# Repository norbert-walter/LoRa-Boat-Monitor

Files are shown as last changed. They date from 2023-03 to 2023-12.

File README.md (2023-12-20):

## LoRa Boat Monitor

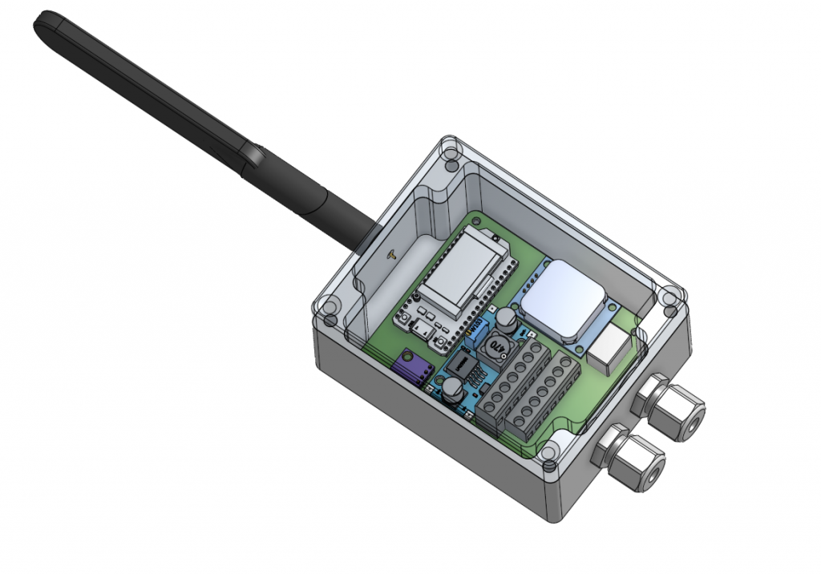
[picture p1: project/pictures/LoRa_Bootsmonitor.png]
LoRa Boat Monitor


Image: LoRa Boat Monitor

Project home page: https://open-boat-projects.org/en/lora-bootsmonitor/

The LoRa boat monitor is used to monitor the boat when it is absent. Various measured values are continuously recorded at freely adjustable time intervals and transferred to the [LoRaWAN](https://www.lora-wan.de/) forwarded. The data is from the TTN server ([The Thinks Network](https://thethingsnetwork.org/)) received in Amsterdam and cached and then sent to [Ubidots](https://ubidots.com/) forwarded as a web frontend. The data transmission is secured by encryption up to Ubidots. The measured data is displayed in Ubidots and various notifications can be sent by email when measured values are exceeded.

There are a large number of [LoRa gateways](https://thethingsnetwork.org/map) which can receive the sent measurement data and forward it to the TTN server. Many LoRa gateways are run by private individuals on a non-profit basis. Anyone who wants can operate their own gateway and make it available to the general public. The radio technology uses the license-free frequency range around 868 MHz and uses a special transmission technology (chirp) to achieve large ranges of up to 50 km at low data rates. The ranges depend on the type of transmission, the antenna height and the environment. In built-up areas such as cities, typical ranges of 1… 4 km are possible. In open environments such as lakes and the sea, up to 50 km can be reached. There are no costs for data transmission when sending LoRa telegrams. This is the big difference to other long range transmission technologies like [SIGFOX](https://www.sigfox.com/) and mobile data networks such as 3G / 4G / 5G. If no LoRa gateway is within range, a simple 1-channel or 3-channel LoRa gateway can be set up with the same board. Only a few components are then left out and a different firmware used. Alternatively, the measured values can also be sent directly to Ubidots via WLAN, provided that a WLAN is within range.

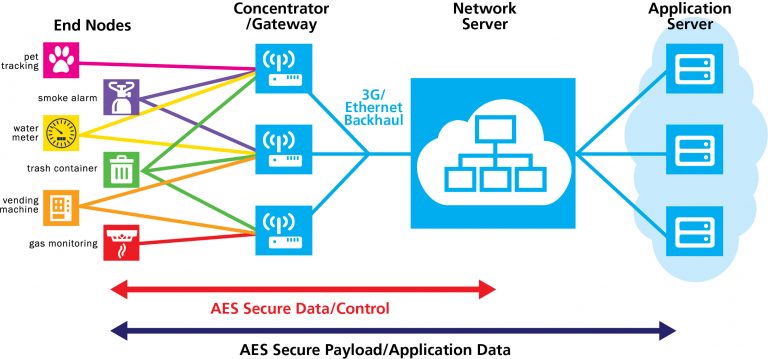
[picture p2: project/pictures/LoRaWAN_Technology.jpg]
LoRa Data Transmission


Image: LoRa data transmission Semtech GmbH

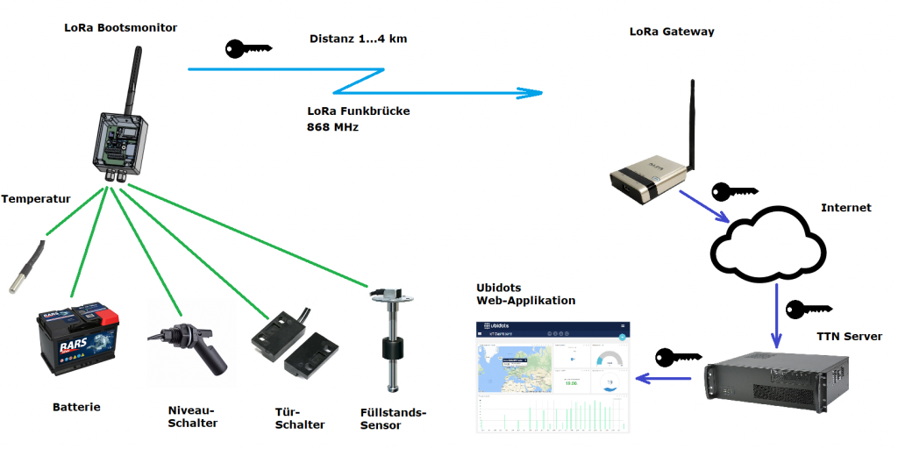
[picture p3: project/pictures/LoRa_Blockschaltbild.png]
LoRa Data Transmission


Image: Block diagram LoRa boat monitor

## The LoRa boat monitor has the following functions:

* 10… 32V supply voltage
* 1.2W power consumption
* LoRa transmitter and receiver with OLED display
* 868 MHz, SF7… SF12, 100 mW transmission power
* Dynamic spreeding factor adjustable SF7… FS10
* Supports channel 0...7 dynamic and fix
* Data transfer rate: 0.3 to 50 kbit / s
* Max. Telegram length for user data: 200 bytes
* Range: built-up area 1… 4km, open area up to 50km
* LoRa transmission interval 30s… 2.1h
* One-channel, three-channel and eight-channel modes can be set
* Feeding the data into The Thinks Network (TTN)
* Parameterization of the LoRa boat monitor possible via return channel (channel, SF, transmission interval, relay)
* WLAN (2.4 GHz) for alternative data transmission
* Web interface for operation
* Firmware update possible via WLAN and Internet
* GPS sensor for geographic location coordinates
* BME280 for measuring temperature, humidity and air pressure
* 1x battery voltage measurement (0… 32V service battery)
* 1x potential-free alarm contact eg for bilge and door monitoring
* 2x tank sensors (0 ... 180 Ohm) with percentage display
* Calibratable tank and voltage sensors
* 1x Reais output for potential-free switching of loads with specified time (5min ... 21h) up to 3A (12V or 230V)
* 2x 1Wire connection for temperature sensors DS18B20 for battery monitoring and refrigerator
* Monitoring and alerting via Ubidots web frontend
* Alerting by e-mail if limit values are exceeded via Ubidots
* Automatic data storage for the last 31 days at Ubidots
* Use of cheap embedded modules
* No SMD components on the board and easy to build
* Board can be ordered here:[https://aisler.net/p/GEIYWWXZ](https://aisler.net/p/GEIYWWXZ)
* Android app

## Create your own code

You have the option of creating your own code using the online [software development environment Gitpod](https://gitpod.io/#https://github.com/norbert-walter/LoRa-Boat-Monitor). Follow this link and a finished development environment similar to PlatformIO will be created that runs in your browser with all code components. To compile the software, enter ***bash run*** in the terminal. In the workspace you will find the compiled binary code under ***.pio/build/heltec_wifi_lora_32_V2/firmware.bin***. With a right click you can download the binary file. You need a account for Gitpod.

## Device flash process

With the [Web Flash Tool](https://norbert-walter.github.io/LoRa-Boat-Monitor/flash_tool/esp_flash_tool.html) you can very easily flash the device with the firmware from the web browser. You need a Chrome or Edge browser and a USB connection cable. If the device is connected to the USB port of the computer, the serial connection can be selected and the flash process can then be started.

## How can I use it?

## What is the current status?

I have completed many tasks but still not everything is perfect so far.

- [x] Technical recherche
- [x] Evaluation of function
    - [x] LoRa trasmission tests
    - [x] Accessibility of gateways
    - [x] Measurement of telegram losses 
    - [x] Test spreeding factors
    - [x] Antenna test
    - [x] TTN configuration
    - [x] Ubitots configutarion and restrictions
- [x] Mechanical design
    - [x] 3D parts für Onshape
- [x] Electronic design
    - [x] Circuit design
    - [x] Board design
    - [x] Customer sample circuit
- [ ] Software
    - [x] Basic functionality for LoRa
    - [x] LoRa back channel for configuration
    - [x] Dynamic spreedung factor
    - [x] Voltage measurement
    - [x] Tank sensors
    - [x] GPS modul
    - [x] BME280
    - [x] Alarm sensors
    - [x] Relay function
    - [x] JSON
    - [x] Web-Updater
    - [x] Web-Configurator
    - [x] Web server as data display
    - [x] VE.Direct support for Victron
    - [ ] Ubidots connection via WiFi
    - [x] NMEA0183 WiFi
    - [x] NMEA0183 Serial
    - [ ] MQTT
    - [x] Andoid App
    - [x] LoRa gateway firmware
    - [x] Migration to TTS V3
- [x] Components ordering
    - [x] Electronic board
    - [x] Mechanical parts
    - [x] Fittings
- [x] Prototyp creation
    - [x] LoRa boat monitor
    - [x] LoRa gateway
- [ ] Production Zero series
    - [ ] DIY Kits
    - [x] Assembled LoRa boat monitor
- [x] Shipping Zero Series
- [x] Documentation
    - [x] Documentation and update server on GitLab
    - [x] Technical description
    - [x] Construction manual
    - [x] Part list
    - [x] User manual
    - [x] Data sheet
    - [x] Flash instructions
- [x] Application tests
    - [x] Temperature 20...40°C
    - [x] LoRa range test (SF7...SF12)
    - [x] WiFi stability test
    - [x] Connection test
    - [x] Long time test
    - [x] User experiences
- [ ] Extensions
    - [ ] Battery current sensor
    - [ ] Actions and alarms depends on events and measuring values
    - [ ] Build a LoRa gateway structure on two towers for the IJsselmeer in Netherlands 
- [ ] Certification
    - [ ] CE Certification

## Questions?

For questions or suggestions please get in contact via email at norbert-walter(at)web.de.

If you like to help or consider this project useful, please donate. Thanks for your support!

Donate

[Donate with PayPal](https://www.paypal.com/cgi-bin/webscr?cmd=_s-xclick&hosted_button_id=5QZJZBM252F2L)

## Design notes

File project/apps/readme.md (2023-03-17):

**Info!** The security guidelines are increased under Android 11 and no third-party apps can be installed via download. The app must be saved in the Downloads folder using a USB cable. The app can then be installed with the Google file manager.

**20210630 LoRa_Boatmonitor_1.apk `(stable)`**

* First App version
* If the App running then disable the display timeout

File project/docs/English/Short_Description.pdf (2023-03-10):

LoRa Boat Monitor

Voltage: 12V (reverse polarity protected, 10 ... 35V DC) Current: 0.1A (0.15A with relay on)
Power: 1.2W
Frequency: 868MHz
Transmission power: 100mW
Antenna: λ / 4, 5dBi, SWR 1.50, 868MHz, SMA
LoRa channel: EU868 dynamic 0 ... 7 or fixed 0 ... 7 (adjustable via return channel) US915 / AU915 dynamic 8 ... 15 or fixed 8 ... 15 (adjustable via return channel) Spreading factor: SF7 ... SF12 (adjustable via return channel)
Send interval: every 300s (5min)
Telegram length: 40 bytes (12 measured values)
GPS: 50 channels, -161dBm, 1Hz, max.2.5m resolution, fix = flashing LED Float switch: closed = 0, open = 1
Temp sensor: -55 ... + 125 ° C, moisture-proof
Relay: 12V / 3A (adjustable via return channel with time limit)
5V output: 2A, short-circuit proof, Attention! Do not connect 12V

Buttons and LEDs LoRa Modul

PRG: programming (without function)
RST: Reset the software, also triggers a telegram transmission and resets the counter LED orange: charge status of the Lipo battery (without function, may light up or flicker) LED white: status of the relay (on: relay active, off: relay inactive)
USB: programming and debug messages, 8N1, 115200Bd

Conector

Alarm
+12V

Alarm
GND

Level
sensor 2
signal,
0-180
Ohm

Level
sensor 2
GND
0-180
Ohm

DS18B20
Temp
sensor,
+5V

DS18B20
Temp
sensor,
1Wire

DS18B20
Temp
sensor,
GND
top | AL | AL | TA2 | GND | +5V | 1W | GND
buttom | +12V | GND | TA1 | GND | NC | C | NO
| Power +12V | Power GND | Level sensor 1 signal, 0-180 Ohm | Level sensor 1 GND | Relay Normaly Close | Relay Center | Relais Normaly Open
AL: | Potential-free digital alarm input (0V high / 12V low) Float switch, door contact, etc.
TA1 / 2: | Tank sensor input 0-180 Ohm
| Caution! Do not connect 12V
1W: | 1Wire data line for external temperature sensor DS18B20 (0 ... 3.3V) Temperature
| monitoring for battery
| Caution! Do not connect 12V
Relay: | Potential-free changeover switch for 12 ... 24V / 3A

Display values

A: Alarm input [1 = 0V, 0 = 12V] C: Telegram counter 0...n
D: Dewpoint [°C]
dT: Send interval [s]
H: rel. Humidity [%]
L: Level value 1 [%]
L2: Level value 2 [%]
P: Air pressure [mbar]
R: State Relay
T: Temperature [°C] (BME280)
T2: Temperature extern [°C] (DS18B20) X: GPS Longitude [° dez]
Y: GPS Latitude [° dez]

Decoding Payload

var counter = ((bytes[1] << 8) | bytes[0]);
var temperature = (((bytes[3] << 8) | bytes[2]) / 100) - 50;
var pressure = ((bytes[5] << 8) | bytes[4]) / 10;
var humidity = ((bytes[7] << 8) | bytes[6]) / 100;
var dewpoint = (((bytes[9] << 8) | bytes[8]) / 100) - 50;
var voltage = ((bytes[11] << 8) | bytes[10]) / 100;
var tempbattery = (((bytes[13] << 8) | bytes[12]) / 100) - 50;
var longitude = ((bytes[15] << 8) | bytes[14]) + ((bytes[17] << 8) | bytes[16]) / 10000;
var latitude = ((bytes[19] << 8) | bytes[18]) + ((bytes[21] << 8) | bytes[20]) / 10000;
var level1 = ((bytes[23] << 8) | bytes[22]) / 100;
var level2 = ((bytes[25] << 8) | bytes[24]) / 100;

Coding Return Channel

The following settings can be made with 3 bytes via the LoRa return channel:

- Byte 0 Change relay state with time function
- Byte 1 Setting of the LoRa spreeding factor
- Byte 2 Setting of the transmission interval

The values for the spreeding factor and transmission interval are permanently saved in the EEPROM and are power off save.

Meaning

The settings must be entered as hexadecimal values for TTN. It is not necessary that all bytes are transmitted. The relay status can also be changed with just one byte.

Byte 0: 0x00...0xFF (0=off, 1...255 * 5 min)
Byte 1: 0x07...0x0A (7...10 = SF7...SF10)
Byte 2: 0x01...0xFF (1...255 * 30s)

Sample:

0x02 0x0A 0x0A
|____ Send interval 300s
|__________ Spreeding faktor SF10 |______________ Relay on for 10 min
0x00 | Relay off
0x00 0x07 | Relay off, SF7

The values for Downlink can be entered in the TTN console under Device. Port 1 should be used and the data should be sent with confirmation. The return channel data is only received by the LoRa boat monitor for 2 seconds after the LoRa measured values have been sent out. Depending on the connection quality and the transmission interval setting, it can take several hours until the information is received by the LoRa boat monitor. The relay switch-on time must be selected carefully, as it may not be possible to switch the relay off again for a short time.

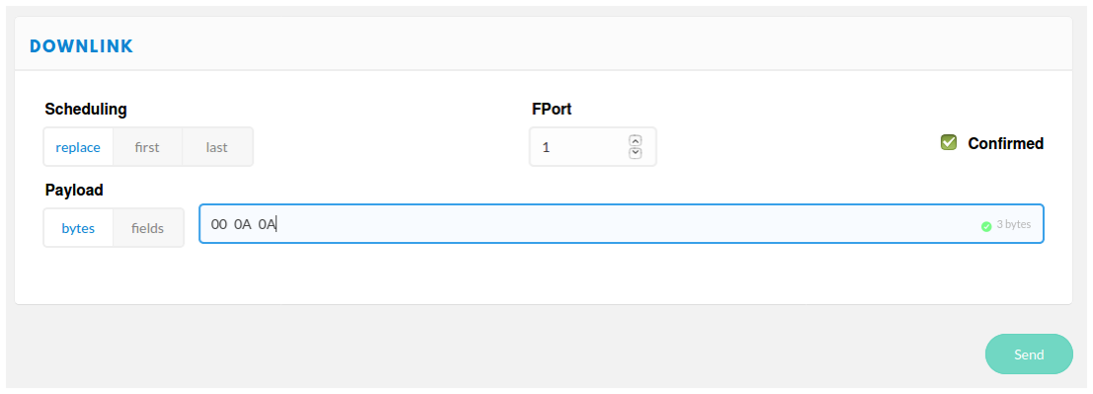
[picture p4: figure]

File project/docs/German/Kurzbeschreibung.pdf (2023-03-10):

LoRa Bootsmonitor

Spannung: 12V (verpolungssicher, 10...35V DC) Strom: 0,1A (0,15A mit Relais an)
Power: 1,2W
Frequenz: 868MHz
Sendeleistung: 100mW
Antenne: λ/4, 5dBi, SWR 1,50, 868MHz, SMA
LoRa-Kanal: EU868 dynamisch 0...7 oder fix 0...7 (über Rückkanal einstellbar) US915 / AU 915 dynamisch 0...7 oder fix 0...7 (über Rückkanal einstellbar) Spreadingfaktor: SF7...SF12 (über Rückkanal einstellbar)
Device-ID: my_device
Device-Address: 12345678
Sendeintervall: alle 300s (5min)
Telegrammlänge: 40 Bytes (12 Messwerte)
GPS: 50 Kanal, -161dBm, 1Hz, max. 2,5m Auflösung, Fix = blinkende LED Schwimmschalter: zu = 0, auf = 1
Tempsensor: -55...+125°C, feuchtigkeitsgeschützt
Relais: 12V / 3A (über Rückkanal mit Zeitbegrenzung einstellbar) 5V-Ausgang: 2A, kurzschlussfest, Achtung! Keine 12V anschließen

Taster und LEDs am LoRa-Modul

PRG: Programmierung (ohne Funktion)
RST: Reset der Software, löst auch eine Telegrammaussendung aus und setzt den Counter zurück LED orange: Ladezustand des Lipo Akkus (ohne Funktion, kann leuchten oder flackern)
LED weiß: Zustand des Relais (an: Relais aktiv, aus: Relais inaktiv)
USB: Programmierung und Debugmeldungen, 8N1, 115200Bd

Klemmenbelegung

Alarm
+12V

Alarm
GND

Tanksensor
2 Signal,
0-180
Ohm

Tanksensor
2 GND
0-180
Ohm

DS18B20
Tempsensor,
+5V

DS18B20
Tempsensor,
1Wire

DS18B20
Tempsensor,
GND
oben | AL | AL | TA2 | GND | +5V | 1W | GND
unten | +12V | GND | TA1 | GND | NC | C | NO
| Power +12V | Power GND | Tanksensor 1 Signal, 0-180 Ohm | Tanksensor 1 GND | Relais Öffner | Relais Mitte | Relais Schließer
AL: | Potenzialfreier digitaler Alarmeingang (0V High / 12V Low) Schwimmschalter, Türkontakt, etc.

TA1/2: Tanksensoreingang 0-180 Ohm
| Achtung! Keine 12V anschließen
1W: 1Wire-Datenleitung für externen Temperatursensor DS18B20 (0...3,3V)
| Temperaturüberwachung für Batterie Achtung! Keine 12V anschließen

Relais: Potenzialfreier Wechselschalter für 12...24V / 3A

Bedeutung im Display

A: Alarmeingang [1 = 0V, 0 = 12V] C: Telegramm-Counter 0...n
D: Taupunkt [°C]
dT: Sendeintervall [s]
H: rel. Luftfeuchtigkeit [%] L: Tankanzeige 1 [%]
L2: Tankanzeige 2 [%]
P: Luftdruck [mbar]
R: Relaiszustand
T: Temperatur [°C] (BME280)
T2: Temperatur extern [°C] (DS18B20) X: GPS Longitude [° dez]
Y: GPS Latitude [° dez]

Dekodierung der Payload

var counter = ((bytes[1] << 8) | bytes[0]);
var temperature = (((bytes[3] << 8) | bytes[2]) / 100) - 50;
var pressure = ((bytes[5] << 8) | bytes[4]) / 10;
var humidity = ((bytes[7] << 8) | bytes[6]) / 100;
var dewpoint = (((bytes[9] << 8) | bytes[8]) / 100) - 50;
var voltage = ((bytes[11] << 8) | bytes[10]) / 100;
var tempbattery = (((bytes[13] << 8) | bytes[12]) / 100) - 50;
var longitude = ((bytes[15] << 8) | bytes[14]) + ((bytes[17] << 8) | bytes[16]) / 10000;
var latitude = ((bytes[19] << 8) | bytes[18]) + ((bytes[21] << 8) | bytes[20]) / 10000;
var level1 = ((bytes[23] << 8) | bytes[22]) / 100;
var level2 = ((bytes[25] << 8) | bytes[24]) / 100;

Codierung Rückkanal

Über den LoRa-Rückkanal können mit 3 Bytes folgende Einstellungen vorgenommen werden:

- Byte 0 Relais-Zustand ändern mit Zeitfunktion
- Byte 1 Einstellung des LoRa-Spreeding-Faktors
- Byte 2 Einstellung des Sendeintervalls

Die Werte für Sreeding-Faktor und Sendeintervall werden dauerhaft im EEPROM gespeichert und sind Power Off save.

Bedeutung

Die Einstellungen müssen als hexadezimale Werte bei TTN eingegeben werden. Es ist nicht notwendig, dass alle Bytes übertragen werden. Der Relais-Zustand kann auch nur mit einem Byte verändert werden.

Byte 0: 0x00...0xFF (0=off, 1...255 * 5 min)
Byte 1: 0x07...0x0A (7...10 = SF7...SF10)
Byte 2: 0x01...0xFF (1...255 * 30s)

Beispiele:

0x02 0x0A 0x0A
|____ Sendeintervall 300s
|__________ Spreedingfaktor SF10 |______________ Relais für 10 min einschalten
0x00 | Relais ausschalten
0x00 0x07 | Relais ausschalten, SF7 verwenden

In der TTN-Console unter Device können die Werte bei Downlink eingegeben werden. Es sollte der Port 1 verwendet und die Daten mit Bestätigung (Confirmed) versendet werden. Die Rückkanaldaten werden immer nur 2s lang nach der Telegrammaussenung der LoRa-Messwerte vom LoRa-Bootsmonitor empfangen. Je nach Verbindungsqualität und Sendeintervall-Einstellung kann es mehrere Stunden dauern, bis die Informationen vom LoRa-Bootsmonitor empfangen werden. Die Relais-Einschaltdauer muss entsprechend vorsichtig gewählt werden, da man unter Umständen das Relais nicht wieder kurzfristig ausschalten kann.


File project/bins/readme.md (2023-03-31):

**20230331 firmware_V1.06.bmb `(actual)`**

* Fix for DS18B20
* WLAN default settings (SSID: NoWa, Pass: 12345678, IP: 192.168.4.1)

**20230312 firmware_V1.05.bmb `(old)`**

* Add boot screen
* Add VE.Direct read and write
* Support for Victron devices with VE.Direct port
* Add NMEA0183 sentences for VE.Direct
* Fix for wrong GPS informations
* Cyclic updating of all information on the OLED display
* Add separate task for LoRa functions
* Stable Web sites
* Project changed from GitLab to GitHub
* WLAN default settings (SSID: NoWa, Pass: 12345678, IP: 192.168.4.1)

`Attention! After update changes all settings to default values. Please renew the settings.`

**20221119 firmware_V1.03.bmb `(old)`**

* Fixing hanging GPS data
* Fixing hanging telegram counter
* Fixing a lot of other bugs
* Validate checksum for NMEA0183 GPS Data and validate RMC content for China fake GPS modul with wrong telegrams
* Add a checksum for TTN upload messages
* Add NMEA0183 output on port 6666 for measuring and GPS values
* All measuring values update permantent on OLED
* Support TTN V3 (TTS)
* WLAN default settings (SSID: NoWa, Pass: 12345678, IP: 192.168.4.1)

`Attention! After update changes all settings to default values. Please renew the settings.`

**20210616 firmware_V1.01.bmb `(old)`**

* Add page for device info, LoRa info and sensor values
* WLAN default settings (SSID: NoWa, Pass: 12345678, IP: 192.168.4.1)

`Attention! After update changes all settings to default values. Please renew the settings.`

**20210530 firmware_V1.00.bmb `(old)`**

* Initial firmware with limited functionality (only settings, no view for measuring results)
* WLAN default settings (SSID: NoWa, Pass: 12345678, IP: 192.168.4.1)

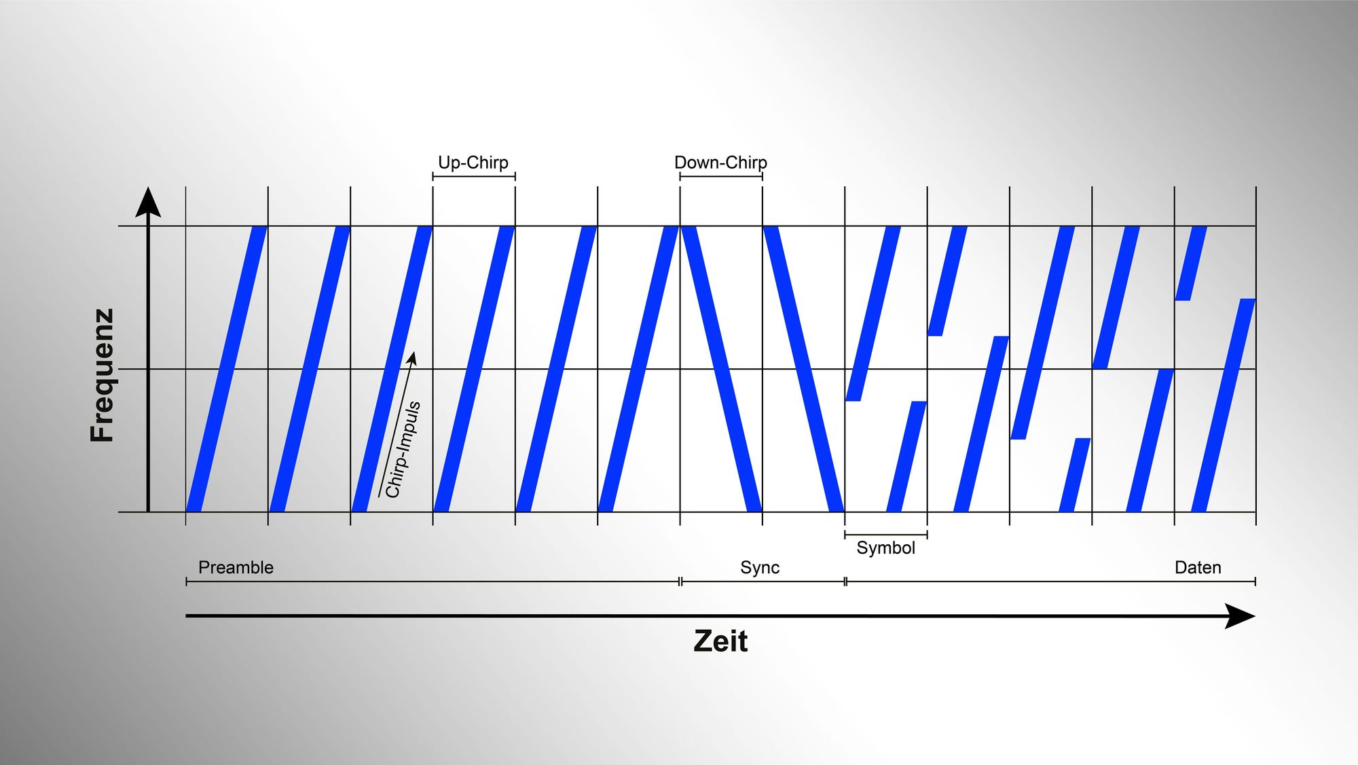
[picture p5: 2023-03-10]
project/pictures/LoRa_Boat_Monitor/Chirp-Spread-Spectrum-Modulation_klein_klein.jpg

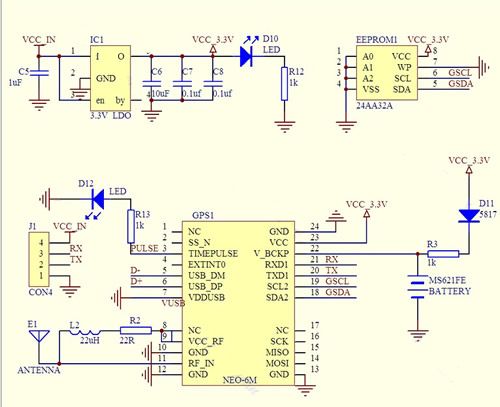
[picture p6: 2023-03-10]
project/docs/Componets/GY-NEO6MV2_schematics.jpg

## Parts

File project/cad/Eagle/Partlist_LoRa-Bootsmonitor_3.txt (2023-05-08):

Stückliste

Menge Wert               Device              Bauteile               
2                        AKL_092_04          X1, X2                 
1                        AKL_092_06          X3                     
1                        LORA32_HELTEC_V2    Q1                     
4     1N4007             BYD13               D1, D2, D5, D7
1     510                R-EU_0207/10        R1 
5     1k                 R-EU_0207/10        R2, R3, R4, R7     
1     5V                 RELAIS 4103E        K1                     
1     P6KE22A            1N4728              D4                     
1     10k                R-EU_0207/10        R5, R8                     
1     33k                R-EU_0207/10        R6                     
1     47u                CPOL-EUE5-8.5       C1                     
1     BC548B             BC548B-NPN-TO92-EBC T1                     
1     BME280             BME280              Q3                     
2     BZX55C3V3          BZX55               D3, D6                 
1     GY-GPS6MV2         GY_GPS6MV2_H        Q2                     
1     LM2596_DCDC        LM2596_DCDC         Q5                     
6     MOUNT-HOLE2,5      MOUNT-HOLE2,5       H5, H6, H7, H8, H9, H10
4     MOUNT-PAD-ROUND3.2 MOUNT-PAD-ROUND3.2  H1, H2, H3, H4         
1     SFH617A-4          SFH610              OK1

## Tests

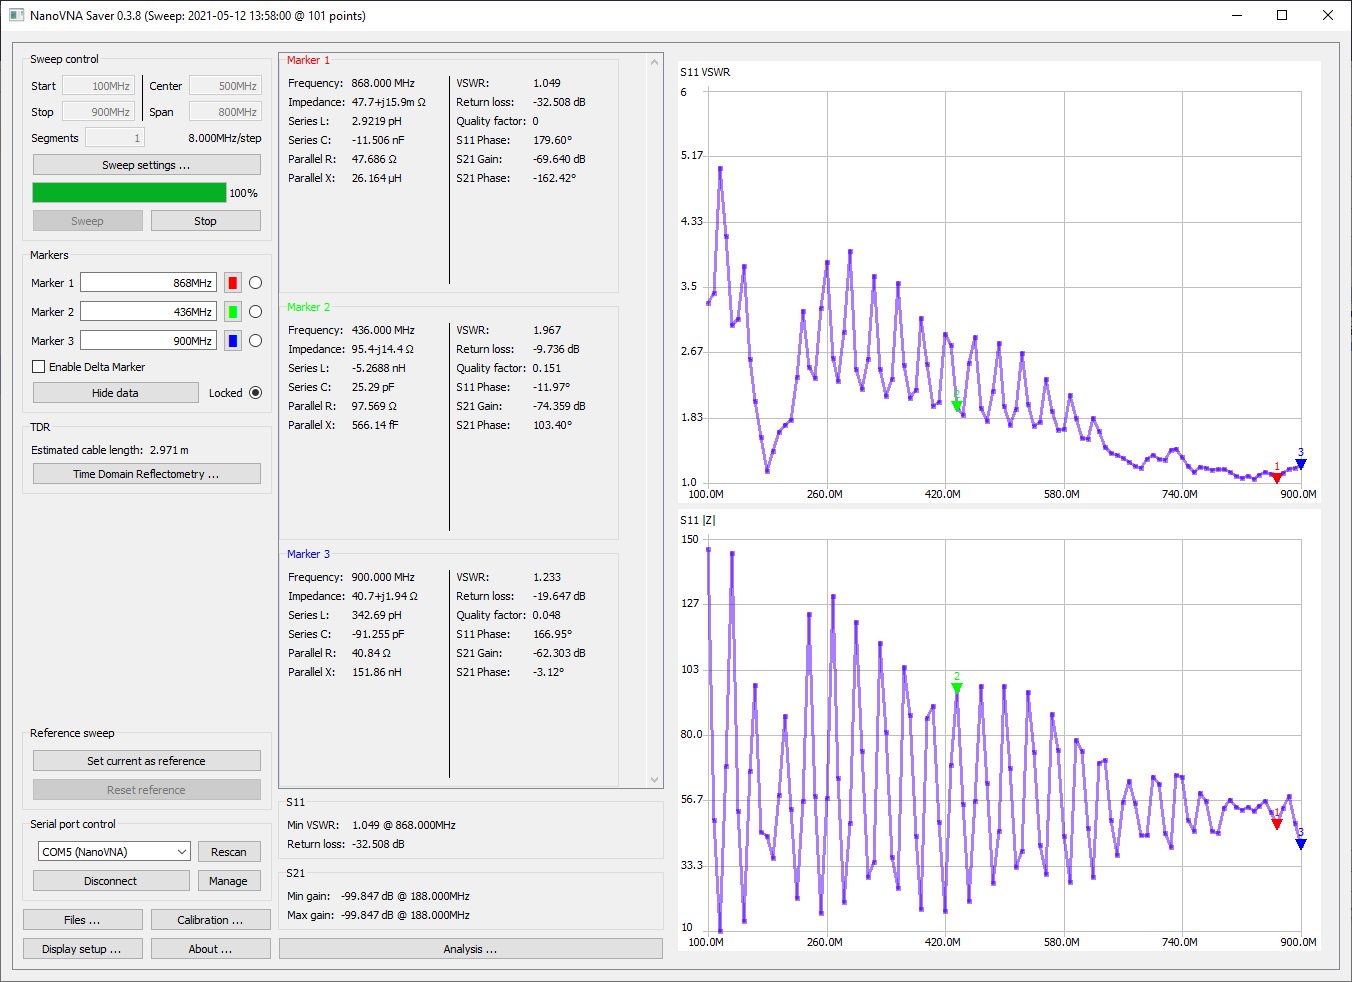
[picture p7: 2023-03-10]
project/pictures/Antenna_Characteristic/Stababtenne_mit_Windungen.png

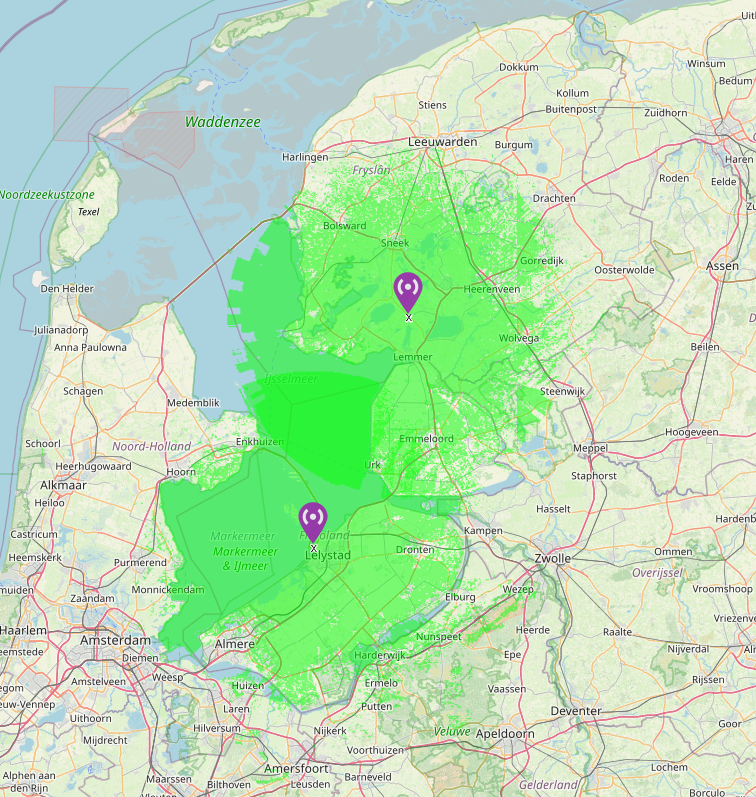
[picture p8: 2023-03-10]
project/pictures/Range_Tests/Abdeckung_IJsselmeer.png

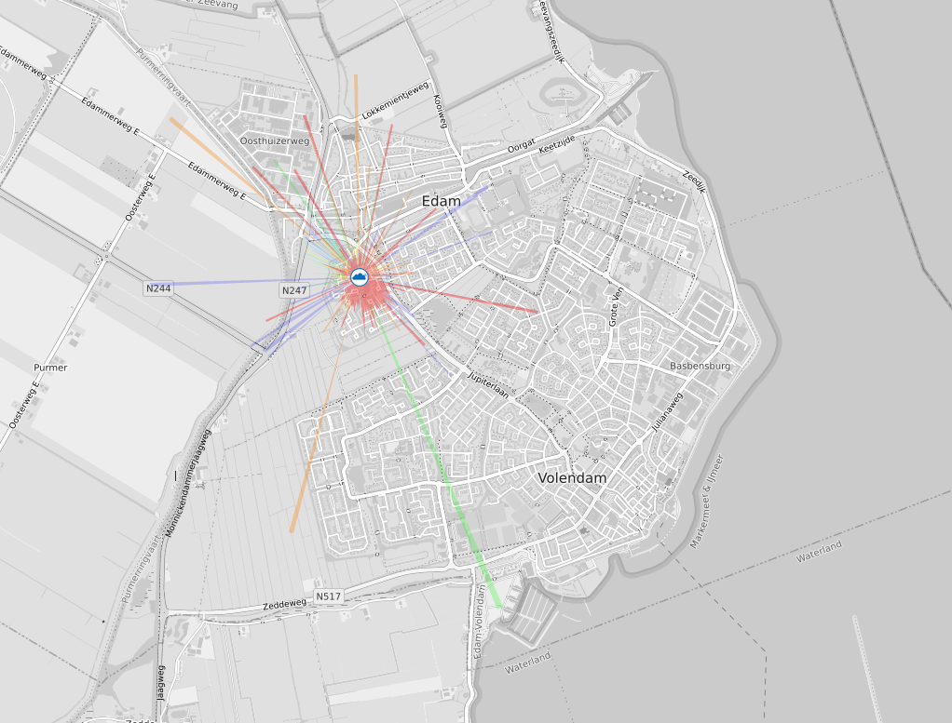
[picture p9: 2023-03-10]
project/pictures/Range_Tests/Reichweitenplot_Volendam.png

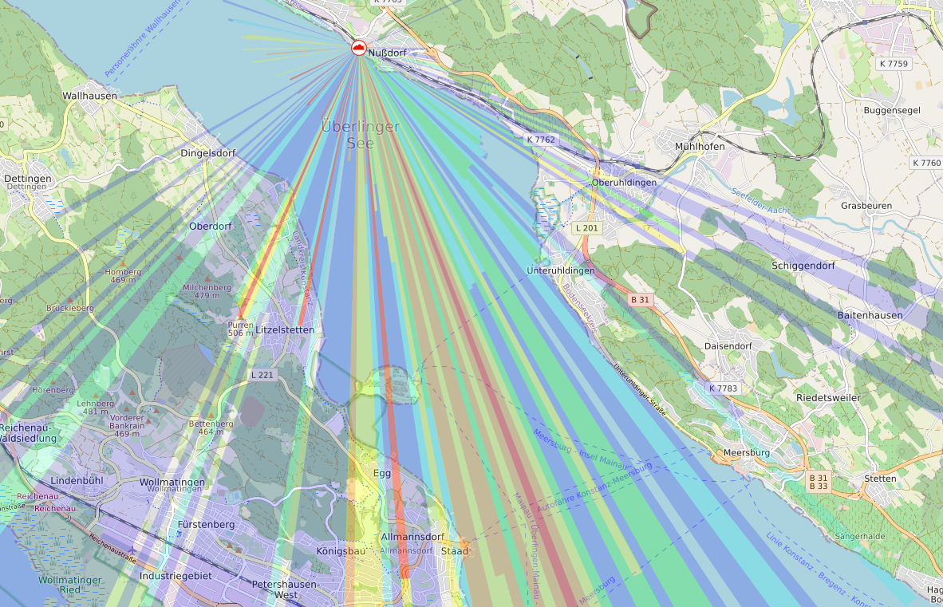
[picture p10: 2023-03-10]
project/pictures/Range_Tests/Nussdorf.png

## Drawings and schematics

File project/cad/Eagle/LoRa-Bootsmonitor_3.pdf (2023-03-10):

A

A

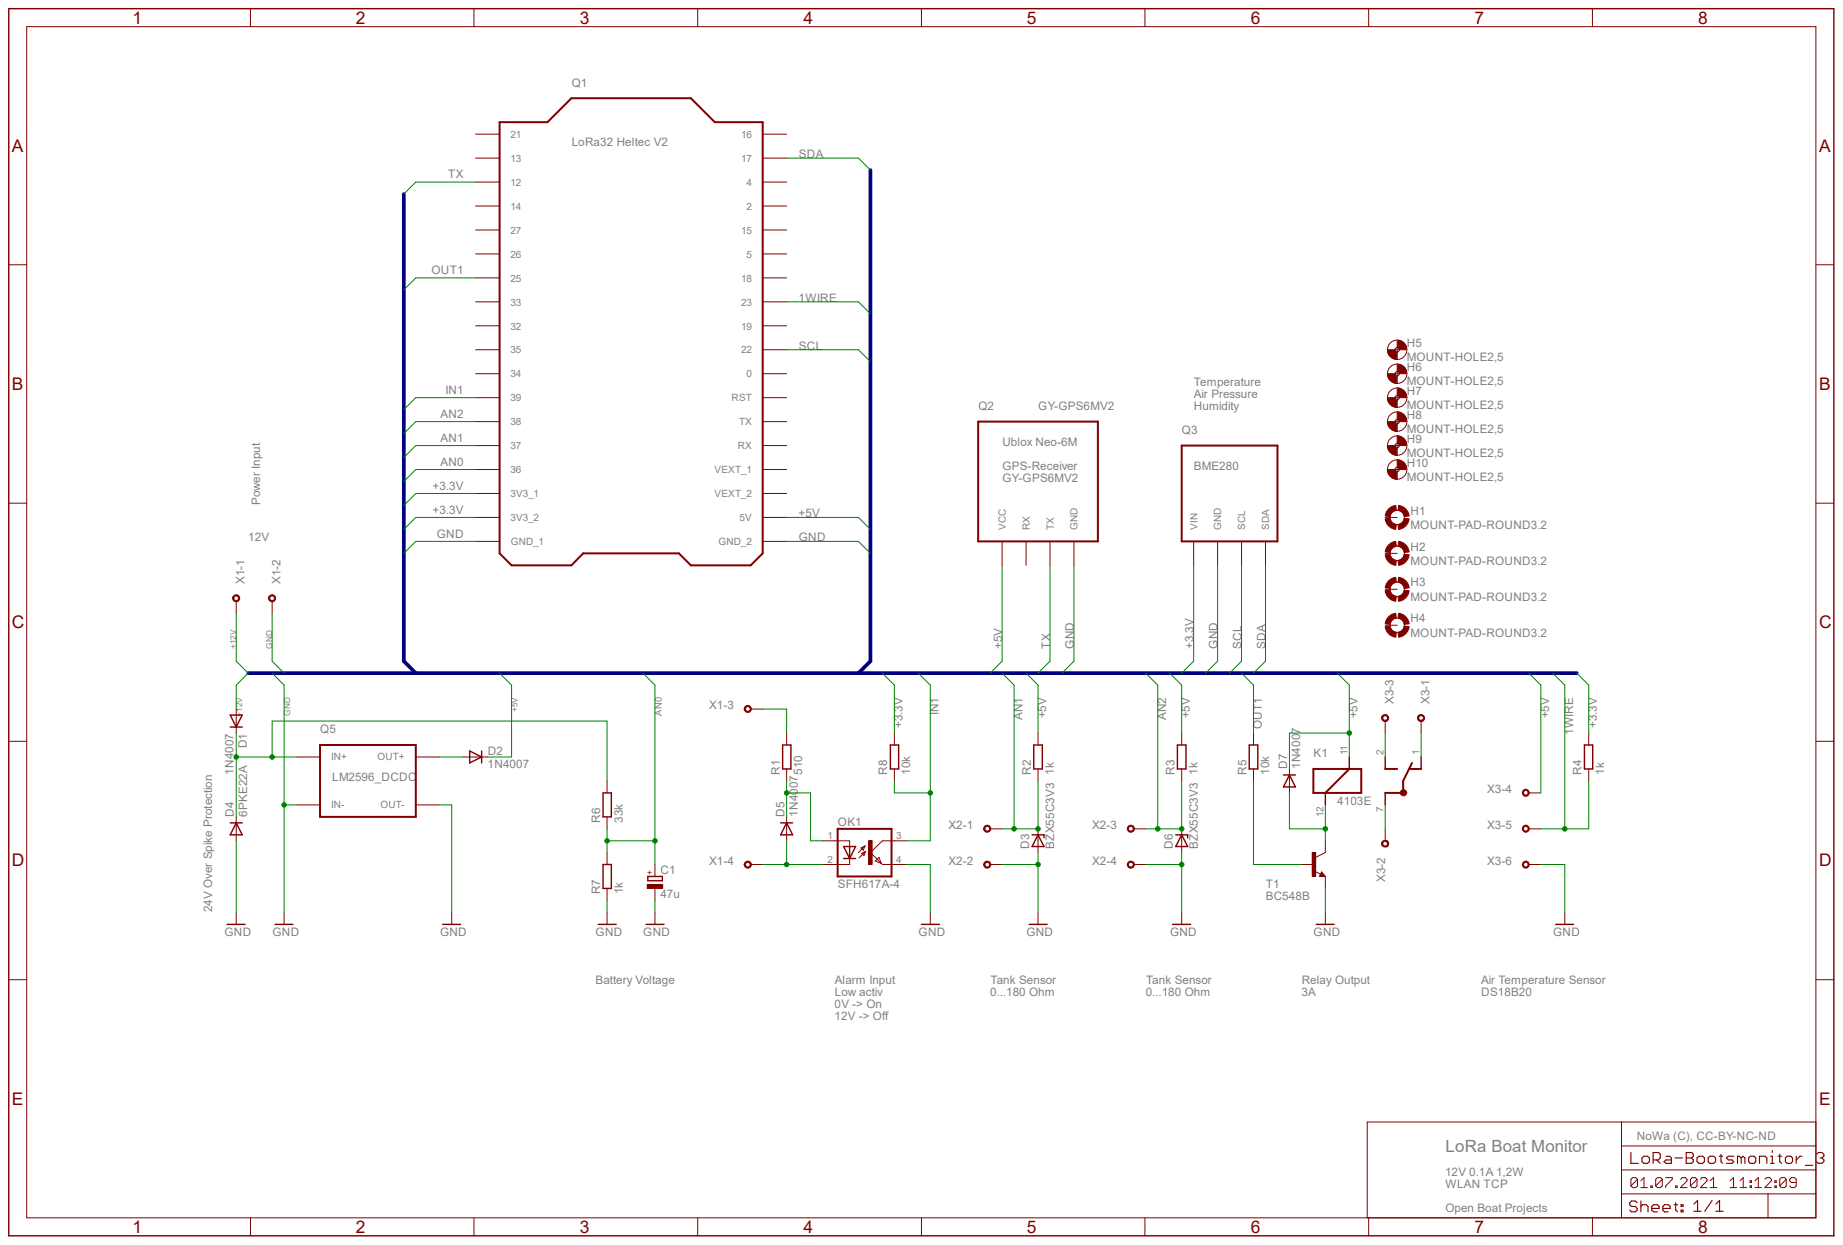
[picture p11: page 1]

NoWa (C), CC-BY-NC-ND

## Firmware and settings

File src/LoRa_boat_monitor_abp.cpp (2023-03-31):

/*******************************************************************************
 * Copyright (c) 2021 Norbert Walter
 * 
 * License: GNU GPL V3
 * https://www.gnu.org/licenses/gpl-3.0.txt
 *
 * LoRa_boat_monitor_abp.ino
 * 
 * Based on work of 2015 Thomas Telkamp and Matthijs Kooijman
 *
 * This uses ABP (Activation-by-personalisation), where a DevAddr and
 * Session keys are preconfigured (unlike OTAA, where a DevEUI and
 * application key is configured, while the DevAddr and session keys are
 * assigned/generated in the over-the-air-activation procedure).
 *
 * Note: LoRaWAN per sub-band duty-cycle limitation is enforced (1% in
 * g1, 0.1% in g2), but not the TTN fair usage policy (which is probably
 * violated by this sketch when left running for longer)!
 *
 * To use this sketch, first register your application and device with
 * the things network, to set or generate a DevAddr, NwkSKey and
 * AppSKey. Each device should have their own unique values for these
 * fields.
 *
 *******************************************************************************
 *
 * Attention! Check for EU868 the settings in:
 * .pio/libdeps/heltec_wifi_lora_32_V2/IBM LMIC framework/src/lmic/config.h
 *
 * Set the #define CFG-eu868 1
 * 
 *******************************************************************************/
 
// Includes
#include <Arduino.h>            // Arduino Environment
#include <WiFi.h>               // WiFi lib with TCP server and client
#include <WiFiClient.h>         // WiFi lib for clients
#include <WebServer.h>          // WebServer lib
#include <ESPmDNS.h>            // mDNS lib
#include <Update.h>             // Web Update server
#include <MD5Builder.h>         // MD5 lib

#include <U8x8lib.h>            // OLED Lib
#include <lmic.h>               // LoRa Lib
#include <hal/hal.h>            // LoRa Lib
#include <Wire.h>
#include <SPI.h>                // SPI/I2C Lib for OLED and BME280
#include <Adafruit_Sensor.h>    // BME280
#include <Adafruit_BME280.h>    // BME280
#include <Ticker.h>             // Timer lib
#include <EEPROM.h>             // EEPROM lib
#include <WString.h>            // Needs for structures
#include <OneWire.h>            // 1Wire lib
#include <DallasTemperature.h>  // DS18B20 lib

#include "Configuration.h"      // Configuration

configData actconf;             // Actual configuration, Global variable
                                // Overload with old EEPROM configuration by start. It is necessarry for port and serial speed
                                // Don't change the position!

#include "Definitions.h"        // Global definitions
#include "GPS.h"                // GPS parsing functions
#include "vedirect.h"           // VE.direct lib
#include "Functions.h"          // Function lib
#include "NMEATelegrams.h"      // Function library for NMEA telegrams
#include "LoRa.h"               // LoRa Lib
#include "task.h"               // Task for LoRa code

#include "icon_html.h"          // Favorit icon
#include "css_html.h"           // CCS cascading style sheets
#include "js_html.h"            // JavaScript functions
#include "main_html.h"          // Main webpage
#include "sensorv_html.h"       // Sensor Values webpage
#include "lora_html.h"          // LoRa Info webpage
#include "settings_html.h"      // Settings webpage
#include "firmware_html.h"      // Firmware update webpage
#include "json_html.h"          // JSON webpage
#include "MD5_html.h"           // JavaScript crypt password with MD5
#include "fwupdate.h"           // Webpage for firmware update
#include "restart_html.h"       // Reset info webpage
#include "devinfo_html.h"       // Device info webpage
#include "error_html.h"         // Error 404 webpage

// Declarations
int value;                      // Value from first byte in EEPROM
int empty;                      // If EEPROM empty without configutation then set to 1 otherwise 0
configData defconf;             // Definition of default configuration data
configData oldconf;             // Configuration stucture for old config data in EEPROM
configData newconf;             // Configuration stucture for new config data in EEPROM

TaskHandle_t Task1;             // Declare task for LoRa code

WebServer httpServer(actconf.httpport);   // Port for HTTP server
MDNSResponder mdns;                       // Activate DNS responder
WiFiServer server(actconf.dataport);      // Declare WiFi NMEA server port

Ticker Timer1;                  // Declare Timer for GPS data reading
Ticker Timer2;                  // Declare Timer for relay ontime
Ticker Timer3;                  // Declare Timer for NMEA sending

void setup() {

  // Create task for LoRa code
  xTaskCreatePinnedToCore(
                    Task1code,  /* Task function */
                    "Task1",    /* Name of task */
                    10000,      /* Stack size of task */
                    NULL,       /* Parameter of the task */
                    1,          /* Priority of the task */
                    &Task1,     /* Task handle to keep track of created task */
                    0);         /* Pin task to core 0 */
  delay(500);

  // Read the first byte from the EEPROM
  EEPROM.begin(sizeEEPROM);
  value = EEPROM.read(cfgStart);
  EEPROM.end();
  // If the fist Byte not identical to the first value in the default configuration then saving a default configuration in EEPROM.
  // Means if the EEPROM empty then saving a default configuration.
  if(value == defconf.valid){
    empty = 0;                  // Marker for configuration is present
  }
  else{
    saveEEPROMConfig(defconf);
    empty = 1;                  // Marker for configuration is missing
  }

  // Loading EEPROM configuration
  actconf = loadEEPROMConfig(); // Overload with old EEPROM configuration by start. It is necessarry for serspeed

  // If the firmware version in EEPROM different to defconf then save the new version in EEPROM
  if(String(actconf.fversion) != String(defconf.fversion)){
    String fver = defconf.fversion;
    fver.toCharArray(actconf.fversion, 6);
    saveEEPROMConfig(actconf);
  }

  //##### Start serial 0 and serial 2 connections #####
  Serial.begin(actconf.serspeed);               // NMEA0183 an debug messages
  delay(200);
  if(String(actconf.envSensor) == "VEdirect-Read" || String(actconf.envSensor) == "VEdirect-Send"){
    Serial1.begin(19200, SERIAL_8N1, RXD1, TXD1); // VE.direct Victron interface (read and write)
  }
  delay(200);
  Serial2.begin(9600, SERIAL_8N1, RXD2, TXD2);  // GPS (NMEA0183)
  delay(200);

  macAddress = ESP.getEfuseMac();
  macAddressTrunc = macAddress << 40;
  chipId = macAddressTrunc >> 40;

  //##### Start OLED #####
  u8x8.begin();
  u8x8.setPowerSave(0);

  u8x8.setFont(u8x8_font_chroma48medium8_r);
  u8x8.clearDisplay();
  u8x8.drawString(0,0,"NoWa(C)OBP");
  u8x8.drawString(11,0,actconf.fversion);
  u8x8.drawString(0,2,"Connection to:");
  u8x8.drawString(0,3,actconf.cssid);
  u8x8.refreshDisplay();    // Only required for SSD1606/7

  // ESP8266 Information Data
  DebugPrintln(3, "Booting Sketch...");
  DebugPrintln(3, "");
  DebugPrint(3, actconf.devname);
  DebugPrint(3, " ");
  DebugPrint(3, actconf.fversion);
  DebugPrintln(3, " (C) Norbert Walter");
  DebugPrintln(3, "******************************************");
  DebugPrintln(3, "");
  DebugPrintln(3, "Modul Type: Heltec LoRa-32");
  DebugPrint(3, "SDK-Version: ");
  DebugPrintln(3, ESP.getSdkVersion());
  DebugPrint(3, "ESP32 Chip-ID: ");
  DebugPrintln(3, chipId);
  DebugPrint(3, "ESP32 Speed [MHz]: ");
  DebugPrintln(3, ESP.getCpuFreqMHz());
  DebugPrint(3, "Free Heap Size [Bytes]: ");
  DebugPrintln(3, ESP.getFreeHeap());
  DebugPrintln(3, "");

  // Debug info for initialize the EEPROM
  if(empty == 1){
    DebugPrintln(3, "EEPROM config missing, initialization done");
  }
  else{
    DebugPrintln(3, "EEPROM config present");
  }

  // Loading EEPROM config
  DebugPrintln(3, "Loading actual EEPROM config");
  actconf = loadEEPROMConfig();
  DebugPrintln(3, "");

  DebugPrint(3, "Sensor ID: ");
  DebugPrintln(3, actconf.deviceID);
  DebugPrintln(3, "Sensor Type: LoRa1000");
  DebugPrintln(3, "Info: LoRa Boat Monitor");
  DebugPrintln(3, "Voltage Input [V]: 0...12 ");
  DebugPrint(3, "Input Pin: GPIO ");
  DebugPrintln(3, ANALOG_IN);
  DebugPrintln(3, "Tank1 [%]: 0...100");
  DebugPrint(3, "Input Pin: GPIO ");
  DebugPrintln(3, TANK1_IN);
  DebugPrintln(3, "Tank2 [%]: 0...100");
  DebugPrint(3, "Input Pin: GPIO ");
  DebugPrintln(3, TANK2_IN);
  DebugPrintln(3, "Temp Sensor: SD18B20 1Wire");
  DebugPrintln(3, "Value Range [°C]: -55...125");
  DebugPrint(3, "Input Pin: GPIO ");
  DebugPrintln(3, OneWIRE_PIN);
  DebugPrint(3, "Temp Unit: ");
  DebugPrintln(3, actconf.tempUnit);
  DebugPrintln(3, "");
  if (String(actconf.envSensor) == "Off") {
    DebugPrintln(3, "Env Sensor: Off");
  }
  if (String(actconf.envSensor) == "BME280") {
    DebugPrintln(3, "Env Sensor: BME280");
  }
  if (String(actconf.envSensor) == "VEdirect-Read") {
    DebugPrintln(3, "Env Sensor: VEdirect reading");
  }
  if (String(actconf.envSensor) == "VEdirect-Send") {
    DebugPrintln(3, "Env Sensor: VE.direct sending");
  }
  DebugPrintln(3,"Serial0 Txd is on pin: "+String(TX));
  DebugPrintln(3,"Serial0 Rxd is on pin: "+String(RX));
  DebugPrintln(3,"Serial1 Txd is on pin: "+String(TXD1));
  DebugPrintln(3,"Serial1 Rxd is on pin: "+String(RXD1));
  DebugPrintln(3,"Serial2 Txd is on pin: "+String(TXD2));
  DebugPrintln(3,"Serial2 Rxd is on pin: "+String(RXD2));
  DebugPrintln(3, "");

  DebugPrint(3, "LoRa Frequency: ");
  DebugPrintln(3, actconf.lorafrequency);
  DebugPrint(3, "LoRa Channel: ");
  DebugPrintln(3, actconf.lchannel);
  DebugPrint(3, "Send Period [x30s]: ");
  DebugPrintln(3, actconf.tinterval);
  DebugPrint(3, "Spreading Factor: ");
  DebugPrintln(3, actconf.spreadf);
  DebugPrint(3, "Dynamic SF: ");
  DebugPrintln(3, actconf.dynsf);
  DebugPrintln(3, "");

//*****************************************************************************************
  // Starting access point for update server
  DebugPrint(3, "Access point started with SSID: ");
  DebugPrintln(3, actconf.sssid);
  DebugPrint(3, "Access point channel: ");
  DebugPrintln(3, WiFi.channel());
//  DebugPrintln(3, actconf.apchannel);
  DebugPrint(3, "Max AP connections: ");
  DebugPrintln(3, actconf.maxconnections);
  WiFi.mode(WIFI_AP_STA);
  WiFi.softAP(actconf.sssid, actconf.spassword, actconf.apchannel, false, actconf.maxconnections);
  hname = String(actconf.hostname) + "-" + String(actconf.deviceID);
  WiFi.hostname(hname);   // Provide the hostname
  DebugPrint(3, "Host name: ");
  DebugPrintln(3, hname);
  if(actconf.mDNS == 1){
    MDNS.begin(hname.c_str());                              // Start mDNS service
    MDNS.addService("http", "tcp", actconf.httpport);       // HTTP service
    MDNS.addService("nmea-0183", "tcp", actconf.dataport);  // NMEA0183 dada service for AVnav
  }
  DebugPrintln(3, "mDNS service: activ");
  DebugPrint(3, "mDNS name: ");
  DebugPrint(3, hname);
  DebugPrintln(3, ".local");

  // Sart update server
  httpServer.begin();
  DebugPrint(3, "HTTP Update Server started at port: ");
  DebugPrintln(3, actconf.httpport);
  DebugPrint(3, "Use this URL: ");
  DebugPrint(3, "http://");
  DebugPrint(3, WiFi.softAPIP());
  DebugPrintln(3, "/update");
  DebugPrintln(3, "");

  #include "ServerPages.h"    // Webserver pages request functions

  // Connect to WiFi network
  DebugPrint(3, "Connecting WiFi client to ");
  DebugPrintln(3, actconf.cssid);

  // Load connection timeout from configuration (maxccount = (timeout[s] * 1000) / 500[ms])
  maxccounter = (actconf.timeout * 1000) / 500;

  // Wait until is connected otherwise abort connection after x connection trys
  WiFi.begin(actconf.cssid, actconf.cpassword);
  ccounter = 0;
  while ((WiFi.status() != WL_CONNECTED) && (ccounter <= maxccounter)) {
    delay(500);
    DebugPrint(3, ".");
    ccounter ++;
  }
  DebugPrintln(3, "");
  if (WiFi.status() == WL_CONNECTED){
    DebugPrint(3, "WiFi client connected with IP: ");
    DebugPrintln(3, WiFi.localIP());
    DebugPrintln(3, "");
    u8x8.drawString(0,4,"Connected IP:");
    u8x8.drawString(0,5, WiFi.localIP().toString().c_str());
    u8x8.refreshDisplay();    // Only required for SSD1606/7
    delay(100);
  }
  else{
    WiFi.disconnect(true);                // Abort connection
    DebugPrintln(3, "Connection aborted");
    DebugPrintln(3, "");
    u8x8.drawString(0,3,"Conection aborted");
    u8x8.refreshDisplay();    // Only required for SSD1606/7
  }

  // Start the NMEA TCP server
  server.begin();
  DebugPrint(3, "NMEA-Server started at port: ");
  DebugPrintln(3, actconf.dataport);
  // Print the IP address
  DebugPrint(3, "Use this URL : ");
  DebugPrint(3, "http://");
  if (WiFi.status() == WL_CONNECTED){
    DebugPrintln(3, WiFi.localIP());
  }
  else{
    DebugPrintln(3, WiFi.softAPIP());
  };
  DebugPrintln(3, "");
//*****************************************************************************************


  //##### Pin Settings #####
  pinMode(ledPin, OUTPUT);          // LED Pin output
  pinMode(relayPin, OUTPUT);        // Relay Pin output
  pinMode(alarmPin, INPUT_PULLUP);  // Alarm Pin input

  //##### Start 1Wire sensors #####
  if (String(actconf.tempSensorType) == "DS18B20") {
    sensors.begin();
  }  

  //##### Cyclic timer #####
  Timer1.attach_ms(5000, readGPSValues);     // Start timer 1 all 5s cyclic GPS data reading
  Timer2.attach_ms(300000, relayTimer);      // Start timer 2 all 5min cyclic counter increment
  Timer3.attach_ms(SendPeriod, sendNMEA);    // Data transmission timer for NMEA

  //####### Starting BME280 ######
  if (String(actconf.envSensor) == "BME280") {
    DebugPrint(3, "BME280 test at address: ");
    DebugPrintln(3, "0x"+String(address, HEX));
    I2CBME.begin(I2C_SDA, I2C_SCL, I2C_SPEED); // Redefinition of I2C pins see Definition.h

    //  if (! bme.begin(address, &Wire)) { // Standard using I2C
    if (! bme.begin(address, &I2CBME)) {
      DebugPrintln(3,"Could not find a valid BME280 sensor, check wiring!");
      //actconf.envSensor = "BME280";

      u8x8.drawString(0,6,"Could not find a");
      u8x8.drawString(0,7,"valid BME280!");
      u8x8.refreshDisplay();    // Only required for SSD1606/7
      delay(10000);
    }
  }
  delay(3000);
  u8x8.clearDisplay();

  //####### Starting LoRaWAN ######
  DebugPrintln(3,"Starting LoRaWAN");
  DebugPrint(3, "LoRa Frequency: ");
  DebugPrintln(3, actconf.lorafrequency);
  DebugPrint(3, "LoRa Channel: ");
  DebugPrintln(3, actconf.lchannel);
  DebugPrint(3, "Send Period [x30s]: ");
  DebugPrintln(3, actconf.tinterval);
  DebugPrint(3, "Spreading Factor: ");
  DebugPrintln(3, actconf.spreadf);
  DebugPrint(3, "Dynamic SF: ");
  DebugPrintln(3, actconf.dynsf);
  DebugPrintln(3, "");

  #ifdef VCC_ENABLE
  // For Pinoccio Scout boards
  pinMode(VCC_ENABLE, OUTPUT);
  digitalWrite(VCC_ENABLE, HIGH);
  delay(1000);
  #endif

  // Set send interval
  TX_INTERVAL = actconf.tinterval * 30;

  // LMIC init
  os_init();
  // Reset the MAC state. Session and pending data transfers will be discarded.
  LMIC_reset();
//  LMIC_setClockError(MAX_CLOCK_ERROR * 1 / 100);
  LMIC_setClockError(MAX_CLOCK_ERROR * 10 / 100);  // For better receiving results

  // Set static session parameters. Instead of dynamically establishing a session
  // by joining the network, precomputed session parameters are be provided.
  #ifdef PROGMEM
  // On AVR, these values are stored in flash and only copied to RAM
  // once. Copy them to a temporary buffer here, LMIC_setSession will
  // copy them into a buffer of its own again.
  uint8_t appskey[sizeof(actconf.appkey)];
  uint8_t nwkskey[sizeof(actconf.nskey)];
  memcpy_P(appskey, actconf.appkey, sizeof(actconf.appkey));
  memcpy_P(nwkskey, actconf.nskey, sizeof(actconf.nskey));
  LMIC_setSession (0x1, actconf.devaddr, nwkskey, appskey);
  #else
  // If not running an AVR with PROGMEM, just use the arrays directly
  LMIC_setSession (0x1, actconf.devaddr, actconf.nskey, actconf.appkey);
  #endif
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
void loop() {
  // Send VE.direct data all 1s
  if(millis() > starttime0 + 1000){
    static int count;
    starttime0 = millis();          // Read actual time
    if (String(actconf.envSensor) == "VEdirect-Send") {
      DebugPrintln(3, "VE.direct Output");
      sendVEdirect();               // Send VE.direct text data
      // ":78DED000B05C4\n"
      int voltageOut = voltage * 100;
      sendBinaryValue(":78DED00", voltageOut); // Send binary data
      if(count == 0){
        sendVEdirectBinary();       // VEdirect binary data (setup and data) al 10 times
      }
    }
    count ++;
    count = count % 10;
  }

/*
  // Mirror all Ve.direct data to serial 0
  int data;
  while (Serial1.available()) {
    //Show VE.direct Daten on serial port 0
    data = Serial1.read();
    Serial.write(data);
  }
*/

  // Read measuring data and display on OLED all 1s
  if(millis() > starttime1 + 1000){
    starttime1 = millis();        // Read actual time

    // BME280 measuerement
    if (String(actconf.envSensor) == "BME280") {
      bme.takeForcedMeasurement(); // has no effect in normal mode
    }

    readValues();
    writeDisplay();
  }

  // Read VE.direct values (BMV-712 tested)
  if (String(actconf.envSensor) == "VEdirect-Read") {
    int rawvoltage = 0;
    char rc;
    String receivedChars;

    if (Serial1.available()) {
      rc = Serial1.read();
      receivedChars += String(rc);
      // Read actual voltage
      if (receivedChars == "V"){
        rawvoltage = Serial1.parseInt();
        if(rawvoltage > 712){
          vedirectVoltage = rawvoltage / 1000.0;
//          Serial.print("VE.direct V: ");
//          Serial.println(vedirectVoltage, 3);
          receivedChars = "";
        }
      }
      // Read actual current
      if (receivedChars == "I"){
        vedirectCurrent = Serial1.parseInt() / 1000.0;
//        Serial.print("VE.direct I: ");
//        Serial.println(vedirectCurrent);
        receivedChars = "";
      }
      // Read actual power
      if (receivedChars == "P"){
        vedirectPower = Serial1.parseInt();
//        Serial.print("VE.direct P: ");
//        Serial.println(vedirectPower);
        receivedChars = "";
      }
      // Read actual SOC
      if (receivedChars == "S"){
        vedirectSOC = Serial1.parseInt();
//        Serial.print("VE.direct SOC: ");
//        Serial.println(vedirectSOC);
        receivedChars = "";
      }
      // Read actual temperature
      if (receivedChars == "T"){
        vedirectTemp = Serial1.parseInt() / 10.0;
//        Serial.print("VE.direct T: ");
//        Serial.println(vedirectTemp);
        receivedChars = "";
      }
      // If line end then clear lina data
      if (rc == '\n'){
        receivedChars = "";
      }
    }
  }

  // HTTP Server-handler for HTTP update server
  httpServer.handleClient();

  // TCP-Server for NMEA0183
  WiFiClient client = server.available();// Check if a client is connected
  int i = 0;

  // While TCP client is connected or Serial Mode is active
  while ((client.connected() && !client.available()) || (int(actconf.serverMode) == 1)) {

    httpServer.handleClient();      // HTTP Server-handler for HTTP update server

    if ((i == 0) && ((int(actconf.serverMode) == 0) || (int(actconf.serverMode) == 4))) {
      DebugPrintln(3, "TCP client connected");
      DebugPrintln(3, "");
    }

    // Read measuring data and display on OLED all 1s
    if(millis() > starttime2 + 1000){
      starttime2 = millis();        // Read actual time

      // BME280 measuerement
      if (String(actconf.envSensor) == "BME280") {
        bme.takeForcedMeasurement();  // has no effect in normal mode
      }  

      readValues();
      writeDisplay();
    }

    // Sending XDR data
    if (flag1 == true){
      i++;
      DebugPrintln(3, "");
      DebugPrint(3, "Send package:");
      DebugPrintln(3, i);

      if((int(actconf.serverMode) == 0) || (int(actconf.serverMode) == 1) || (int(actconf.serverMode) == 4)){
         if(int(actconf.senddata) == 1){
            if (String(actconf.envSensor) == "BME280") {
              client.println(sendXDR1(1));  // Send XDR1 telegram environment sensors
            }
            client.println(sendXDR2(1));    // Send XDR2 telegram battery sensors
            client.println(sendXDR3(1));    // Send XDR3 telegram level and control
            if(nmea != ""){
              client.println(sendRMC(1));   // Send GPS RMC telegram
            }
         }
      }
      flag1 = false;                        // Reset the send flag
    }
  }

}

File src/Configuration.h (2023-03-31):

#ifndef Configuration_h
#define Configuration_h

// Default configuration
// Types 'byte' und 'word' doesn't work!
typedef struct {
  int valid = 8;                            // Number of configuration (Please change when the structure or values are changed)
  int crypt = 0;                            // Activate for critical webside a password query [0 = off|1 = on]
  char password[31] = "12345678";           // Password for critical websides (settings, update and reboot)
  char devname[21] = "LoRa Boat Monitor";   // Device name for web configuration
  char crights[14] = "NoWa (C) 2023";       // Copy rights
  char fversion[6] = "V1.06";               // Firmware version
  char license[12] = "GPL3";                // License type
  int debug = 3;                            // Debug mode 0=off 1=Errors 2=Errors + Warnings 3=Errors + Warnings + Messages
  char cssid[31] = "MyBoat";                // SSID of WiFi Client
  char cpassword[31] = "S6587rr94P";        // Password of WiFi Client
  int timeout = 30;                         // Connection timeout for client in [s] [30|90|120|150|180|210|240|270|300]
  char sssid[31] = "NoWa";                  // SSID of WiFi Server
  char spassword[31] = "12345678";          // Password of WiFi Server
  int apchannel = 1;                        // Assess Point channel [1...13]
  int maxconnections = 2;                   // Max number of connection for WiFi clients [1...4]
  int mDNS = 1;                             // Using mDNS service [0|1] 0=off, 1=on
  char hostname [31] = "boatmonitor";       // Hostname WiFi Server
  int dataport = 6666;                      // Port for NMEA data output
  int httpport = 80;                        // Port for HTTP and update pages
  int serverMode = 0;                       // Used server mode [0|1|2] 0=LoRa (HTTP, JSON, NMEA), 1=NMEA Serial, 2=Demo (Simulation data)
  int serspeed = 115200;                    // Serial speed in [Bd] 8N1 [300|1200|2400|4800|9600|19200|38400|57600|74880|115200]
  int skin = 0;                             // Skin for websides [0|1|2]

  // LoRaWAN device, network and session key
  u4_t devaddr = 0x12345678;                // LoRa device address
  u1_t nskey[16] = { 0x11, 0x22, 0x33, 0x44, 0x55, 0x66, 0x77, 0x88, 0x99, 0xAA, 0xBB, 0xCC, 0xDD, 0xEE, 0xFF, 0x00 };  // LoRa Network session key
  u1_t appkey[16] = { 0x11, 0x22, 0x33, 0x44, 0x55, 0x66, 0x77, 0x88, 0x99, 0xAA, 0xBB, 0xCC, 0xDD, 0xEE, 0xFF, 0x00 }; // LoRa Application Key


  char lorafrequency[6] = "EU868";          // LoRa frequency region [EU868|US915]
  int lchannel = 1;                         // Used LoRa channel [0...7|8|9] 0...7 single channel mode, 8 dynamic channel mode with channel 0...7, 9 dynamic channel mode with channel 0...2
  int spreadf = 10;                         // Spreading factor (SF) [7|8|9|10]
  int dynsf = 1;                            // Dynamic spreading factor [0|1] 0=off, 1=on (transmit schema SF SF SF SF SF SF SF SF SF SF SF+1 SF+2)
  int tinterval = 1;                        // LoRa transmit interval x30s, [1...255] (value x 30s, 10 X 30s = 300s = 5min)
  int sendlora = 1;                         // Send LoRa telegrams [0|1] 0=off 1=on
  int relay = 0;                            // Relay status [0|1] 0=off 1=on
                                            // Info: see relaytimer [0|1...255] 0=off 1...255= value x 5min on time for relay

  int instrumentSize = 400;                 // Instrument size X * Y [pix] [200|250|300|350|400|450|500|550|600]
  int deviceID = 0;                         // ID of LoRa device [0...9]
  char deviceType[10] = "LoRa1000";         // Type of LoRa boat monitor [LoRa1000]
  int senddata = 1;                         // Send sensor data to NMEA0183 [0|1] 0=off 1=on (WIMWV, WIVWR, WIVPW, PWINF) for Serial or JSON
  int sendubidots = 0;                      // Send telegrams to Ubidots [0|1] 0=off 1=on

  float voffset = 6.47301;                  // Voltage offset [V]
  float a1vslope = 0.02860676;              // Volatge calibration coefficient a1
  float a2vslope = 0;                       // Volatge calibration coefficient a2
  int vaverage = 1;                         // Volatge number of values for average building [1...100]

  float t1offset = 0;                       // Tank1 offset [l]
  float a1t1slope = 143.1974;               // Tank1 calibration coefficient a1
  float a2t1slope = 0;                      // Tank1 calibration coefficient a2
  int t1average = 1;                        // Tank2 number of values for average building [1...100]

  float t2offset = 0;                       // Tank2 offset [l]
  float a1t2slope = 143.1974;               // Tank2 calibration coefficient a1
  float a2t2slope = 0;                      // Tank2 calibration coefficient a2
  int t2average = 1;                        // Tank2 number of values for average building [1...100]
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

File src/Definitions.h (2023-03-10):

#ifndef Definitions_h
#define Definitions_h

// Passwort settings
String transactionID = String(random(0, 99999999));// Generate a random transaction ID by initialisation
String raw = "";                    // Uncrypted raw data
String md5crypt = "";               // Crypted data

//MAC Address
uint64_t macAddress;                // MAC address equivalent to Chip-ID
uint64_t macAddressTrunc;           // Truncated MAC address
uint chipId;                        // Chip-ID as part from MAC address

// EEPROM settings (max size is 4096 Byte)
int cfgStart = 1024;                // Start adress in EEPROM (Attention! The first 32 Byte are used beginning with adress 0)
int sizeEEPROM = 2048;              // Used size of EEPROM 2kB (limit for config file size)

// WLAN client settings
String hname;                       // Hostname
int maxccounter;                    // Maximum number for connection tests until aborted (maxcounter = 60; 60 * 500ms = 30s waiting time)
int ccounter;                       // Actual connection test counter

// Settings for NMEA server 
int SendPeriod = 2000;              // SendPeriod in [ms], Attention! Range is limited [2000]
volatile bool flag1 = false;        // Flag for data sending

// LoRa timeslot counter for different spreading factors
long slotcounter = 0;               // Slot counter
int slot = 0;                       // Actual time slot
int sf = 7;                         // Actual spreading factor
int actlorachannel = 0;             // Actual LoRa channel
byte rpayload[200];                 // Received LoRa payload over downlink (array of 200 bytes)

// Measuring values
long starttime0 = millis();         // Timer0 value for measuring loop
long starttime1 = millis();         // Timer1 value for measuring loop
long starttime2 = millis();         // Timer2 value for measuring loop
float fieldstrength;                // WLAN field strength
float quality;                      // WLAN quality
float temperature;                  // Temperature in [°C]
float pressure;                     // Pressure in [hPa]
float humidity;                     // Himidity in [%]
float dewp;                         // Dewpoint in [°C]
float voltage;                      // Battery voltage in [V]
float capacity;                     // Battery capacity in [%]
float tank1;                        // Tank 1 level [V]
float tank2;                        // Tank 1 level [V]
float tank1p;                       // Tank 2 level [%]
float tank2p;                       // Tank 2 level [%]

int alarm1;                         // Digital Alarm input
int relaytimer = 0;                 // Relay timer for ontime n x 5min
float temp1wire = 0.0;              // Temperature 1Wire in [°C]
float temp1wireold = 0.0;           // Old temperature 1Wire in [°C]
float latitude = 0.0;               // Latutude in decimal notation
float longitude = 0.0;              // Longitude in decimal notation
float altitude;                     // Altitude [m]
String latitudeNS = "";             // Latitude direction N|S
String longitudeEW = "";            // Longitude direction E|W
int hour = 0;                       // Hour GPS
int minute = 0;                     // Minute GPS
int second = 0;                     // Second GPS
int day = 0;                        // Day GPS
int month = 0;                      // Month GPS
int year = 0;                       // Year GPS
int gpsspeed = 0;                   // Speed GPS
int course = 0;                     // Course GPS


// uint16_t valus for payload coding
uint16_t counter16 = 0;
uint16_t temperature16 = 0;
uint16_t pressure16 = 0;
uint16_t humidity16 = 0;
uint16_t altitude16 = 0;
uint16_t dewp16 = 0;
uint16_t voltage16 = 0;
uint16_t temp1wire16 = 0;
uint16_t longitude16_1 = 0;
uint16_t latitude16_1 = 0;
uint16_t longitude16_2 = 0;
uint16_t latitude16_2 = 0;
uint16_t tank1_16 = 0;
uint16_t tank2_16 = 0;

// Analog input 0...3.3V => 0...33V => 0...4096
const int ANALOG_IN = 36;     // Analog input GPIO36 Voltage
const int TANK1_IN = 37;      // Analog input GPIO37 Tank 1
const int TANK2_IN = 38;      // Analog input GPIO38 Tank 2

// Output Pins
const int ledPin = 25;        // Pin GPIO25, LED is high activ
const int relayPin = 25;      // Pin GPIO25, Relay is high activ

// Input Pins
const int alarmPin = 39;      // Pin GPI39, Alarm input

// 1Wire definitions
#define OneWIRE_PIN 23        // 1Wire on pin GPIO23
OneWire DS18B20(OneWIRE_PIN); // Declare 1Wire port
DallasTemperature sensors(&DS18B20);// Declare 1Wire sensor

// Serial port 1 pin definitions for VE.direct from Victron
#define RXD1 17               // VE.direct RX GPIO17
#define TXD1 22               // VE.direct TX GPIO22

// Serial port 2 pin definitions for GPS
#define RXD2 12               // GPS TX GPIO12
#define TXD2 13               // GPS RX GPIO13
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

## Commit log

2023-03-10 Add project informations and data
    [LoRa-Bootsmonitor_3.brd, LoRa-Bootsmonitor_3.sch]
2023-03-31 change file name
    [Configuration.h]
